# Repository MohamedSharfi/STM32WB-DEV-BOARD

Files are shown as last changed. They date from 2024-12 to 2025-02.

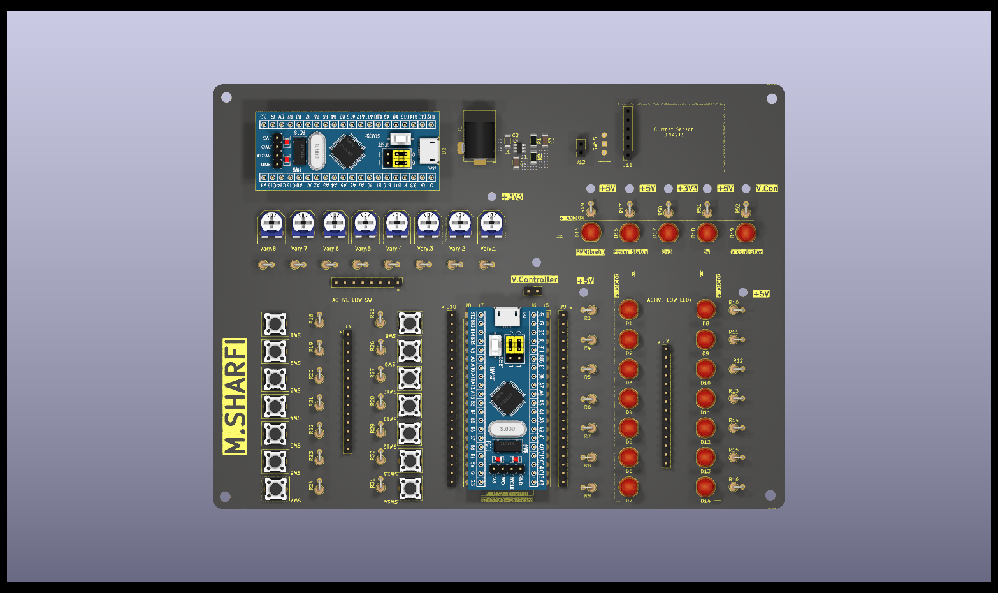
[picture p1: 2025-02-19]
TestBoard/TestBoard.png

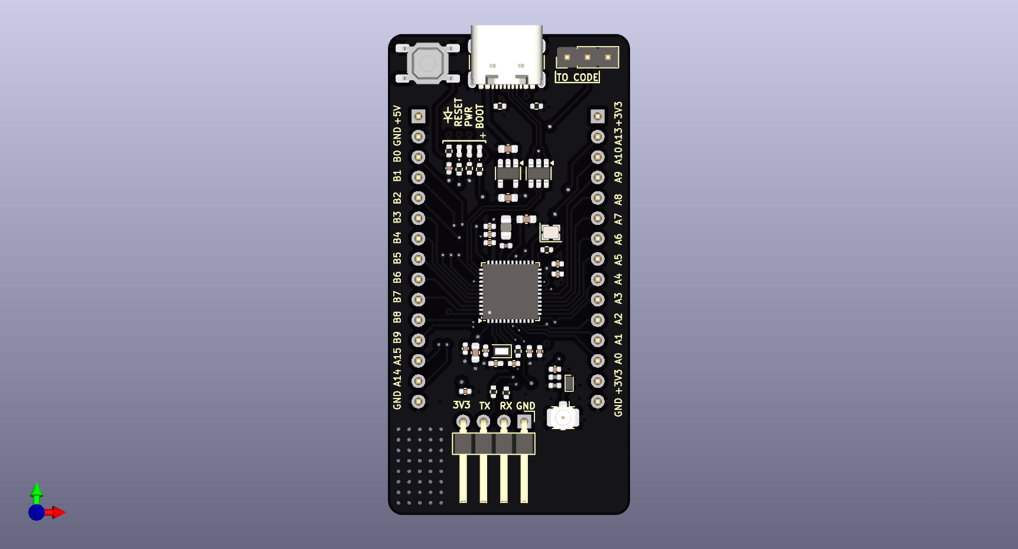
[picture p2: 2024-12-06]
3DPictures/STM32.png

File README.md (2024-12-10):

# STM32 Development Breadboard Prototype 
This repository contains the schematic, PCB design, and documentation for an STM32-based development prototype designed for breadboard testing and prototyping.

## Project Status
     Schematic    :  100% Complete
     PCB Design   :  100% Complete
     Documentation:  100% Complete

## Table of Contents
Overview
Features
Getting Started
Project Files
Documentation
Contributing
License
Overview
This project aims to provide a robust STM32 development environment optimized for breadboard prototyping. It's ideal for my next projects development & testing.

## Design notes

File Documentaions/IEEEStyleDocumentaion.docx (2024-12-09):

STM32 Board Design

Mohamed Sharfi Abdelgadir Omer
Electrical Engineering Student , Universiti Teknologi Malaysia

Abstract—This electronic document is a DETAILED report about the design and development of STM32 PCB board starting from the schematic until the last Gerber files, any more updates of the board and manufacturing process will be added to this report.

Keywords—STM32WB, PCB design, Design Rules, Schematic, layout.

# I. Introduction

STM32, made by STMicroelectronics, is one of the leading products in the industry for microcontroller chip manufacturing. It is crucial for students to learn how to design schematics and layouts for PCBs that meet all the standards set by STMicroelectronics for their microcontrollers. After design process, it is important to test it thoroughly before using it in a project to minimize the time needed for troubleshooting in the future, this paper will focus on the main component design of the schematic of the microcontroller as a development that can be used for future prototypes.

# II. Chip Used

STM32WB55 is an 32-bit Arm®-based Cortex® with Bluetooth 5.4 and IEEE802.15.4 Radio.

It uses 2.4Ghz frequency and can support up to 3.6V.It has a 30 pins GPIO, 12bit ADC with 13 channels (incl. 3 internal) with an internal Vref. It also has a 16-bit timer, one general purpose 32-bit timer, two 16-bit basic timers, two low power timers, two watchdog timers , and a SysTick timer which all of them supports direct memory access (DMA). The Clock sources are 32Mhz crystal oscillator (integrated trimming capacitors) as a radio and CPU clock and 32khz for RTC. The internal Memories, up to 1MB flash memory 256KB sRAM , USART , SPI , I2C and USB interfaces for bootloader.

The Microcontroller is capable of handling the intended projects and its suitable for wireless base friendly projects

# III. Schemtic design

## A. Power sources.

The Main sources for power will be a USB-C which can deliver 5V, but Microcontroller can handle up to 3.6 and it’s recommended to operate at 3.3v so we will regulate that voltage using a linear regulator although the efficiency isn’t the best but its suitable for small low-cost applications.

The chip used is MIC5365-3.3YD5 which has two 4.7uf capacitors and referring to the datasheet both capacitors are used for stability and ripple minimizing purposes.

The regulator can be turned on using the enable pin which is active high that can handle up to Vin, which is 5v,

Lastly an LED has been added to indicate when power is on the next figure shows the circuit of the power regulator.

Then to power the microcontroller we first need to add a couple of decoupling capacitors. The power traces can be affected by EMI and stray inductance which can lead to some fluctuations, Sparkes or noise in the input voltage in the microcontroller

The STM32 datasheet recommended that a bulky capacitor which is 4.7uf need to be placed before the power pins in addition with an 100nf small decoupling capacitor for each pin.

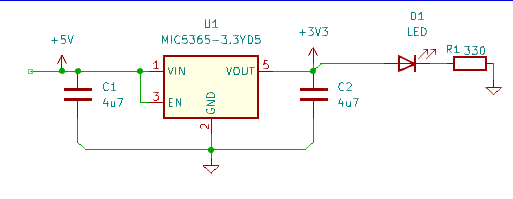
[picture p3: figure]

Figure ‎III-1 Circuit of the power regulator

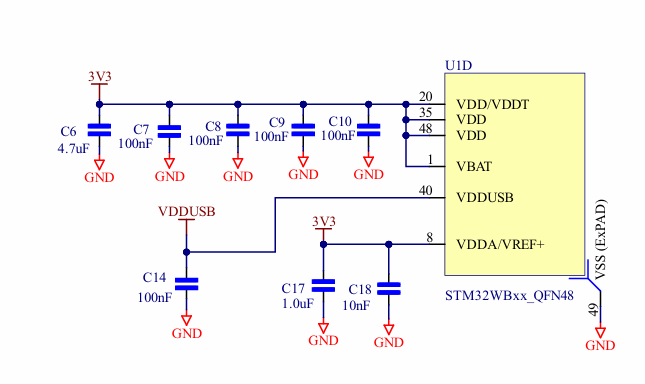
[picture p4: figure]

Figure ‎III-2 Recommended Decoupling capacitor

## B. RF and The antenna.

Referring to the section 3.6.4 from the stm32 datasheet RF pin description the RF pin must be connected to the antenna through a low-pass matching network since the Impedance of the RF chip (Zsource) isn’t 50 ohm but (42-19j Ohm) and referring to the Application note AN5165 figure 8 reference board the matching network used is Low-Pass ∏-Shaped with a Low Pass Filter DLF162500LT-5028A1in series and finally ending with an antenna which is an SMD coaxial connector.

Since the LPF chip isn’t available in KiCad and it’s a critical component a new symbol and footprint needed to be designed and added to the KiCad library.

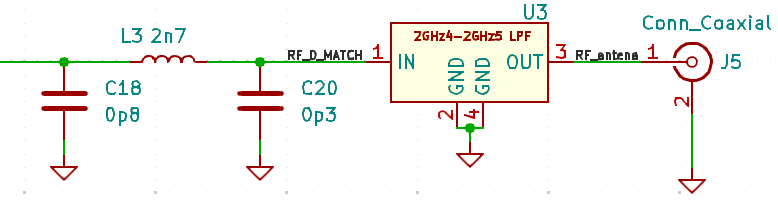
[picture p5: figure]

Figure ‎III-3 Matching Network and LPF circuit

## C. Reset Button

6.3.18 NRST pin characteristics (STM32WB datasheet) clearly shows the circuit for the reset pin NRST which is an Active low pin pulling down will lead to the system to reset.

The recommended circuit is a push button in parrel with a capacitor in order to minimize the debouncing effect, With the recommended circuit an active low LED has been added to indicate the status of the reset pin.

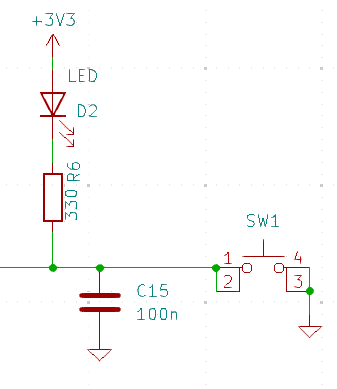
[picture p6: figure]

Figure ‎III-4 Active Low reset button circuit

## D. USB-C connector.

For communication with the Chip, media streaming, Power supply and programming an USB-C connector is needed.CC pins in the type C connector are responsible for determining if your device is receiving power or supplying, and in this case the connector is our main supplier for power, so we need to configure the pins as so. And to do that the pins need to be pulled down. (4.2.5 Configuration Pins). For the ESD we used which is a package containing 5 TVS Diode

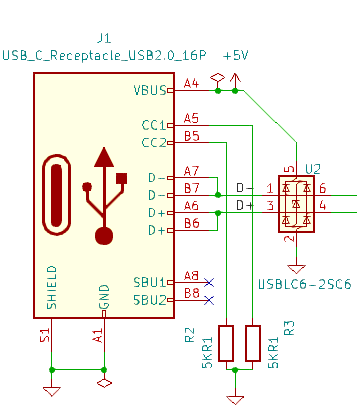
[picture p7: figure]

Figure ‎III-5 USB-C Circuit

## E. Crystal oscillator.

According to the microcontroller datasheet (6.3.10 External clock source characteristics) the high-speed external (HSE) clock should be supplied with a 32 MHz crystal oscillator and the low-speed external (LSE) clock can be supplied with a 32.768 kHz crystal resonator oscillator. Load capacitors affect the resonant frequency and determine the oscillation's stability and phase noise, for the HSE the microcontroller have an integrated tunable load capacitors but for the LSE external load capacitors are needed and referring to AN5165 those value of load capacitors should be 10pF each

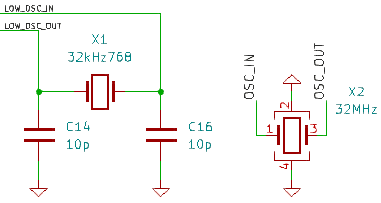
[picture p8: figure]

Figure ‎III-6 crystal oscillator circuits

## F. Switched Mode Power Supply (SMPS).

The device integrates an SMPS step-down converter to improve low power performance

when the VDD voltage is high enough. This converter has an intelligent mode that automatically enters in bypass mode when the VDD voltage falls below a specific BORx (x = 1, 2, 3 or 4) voltage.

By default, at reset, the SMPS is in bypass mode.

The device can be operated without the SMPS by just wiring its output to VDD. This is the case for applications where the voltage is low, or where the power consumption is not critical.

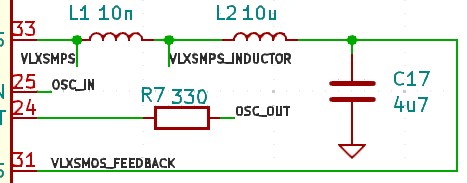
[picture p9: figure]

Figure ‎III-7 SMPS circuit

## G. Boot & program mode

PH3 pin that’s according to the manual is the pin responsible of changing the STM32 statue from normal to bootloader that must be pulled up in order to program the chip using UART. So simply the circuit is an active high 3 pin headers so that when u short the first two STM32 goes to the programming state and if its left floating or grounded it will let the pin operate in normal mode. Additionally, an active high LED is connected to indicate the state of the pin.

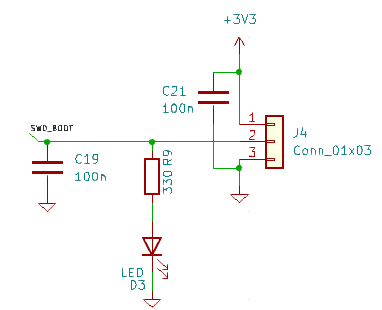
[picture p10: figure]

Figure ‎III-8 PH3 pin

## H. I/O interface

Lastly a 1x15 pin header is added for the GPIO and a 1x4 pin header is added for the UART.

# IV. The Schemtic

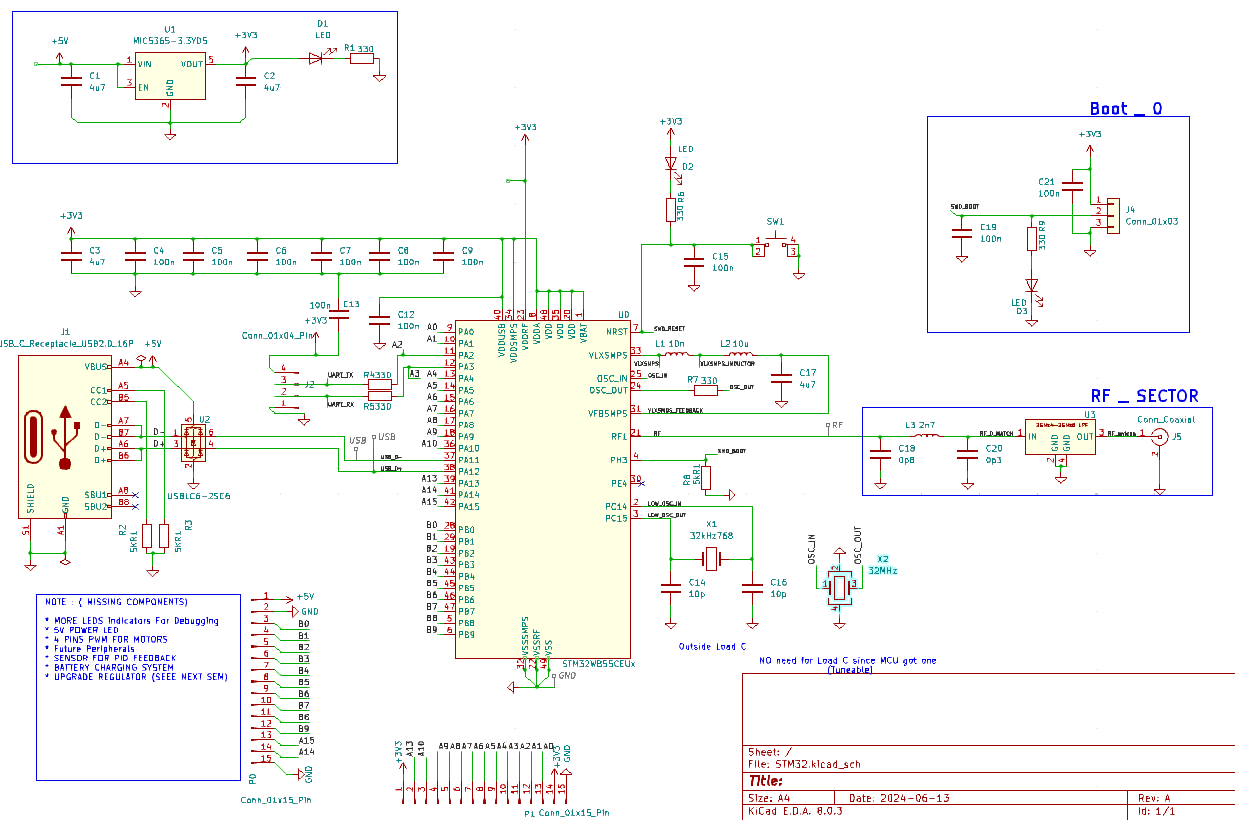
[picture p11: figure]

Figure ‎IV-1 Overall Schematic design

# V. References

[1] Load Capacitance: The Key to Precision in Crystal Units. Avalible : https://www.siward.com/en/about/industry/Load_Capacitance__The_Key_to_Precision_in_Crystal_Units.
[2] AN2606-Application note-STM32 microcontroller system memory boot mode.
[3] STM32WB. Available: https://www.st.com/en/microcontrollers-microprocessors/stm32wb-series/documentation.html.
[4] STMicroelectronics: USBLC6-2.
[5] Universal Serial Bus Type-C Cable and Connector Specification.Avaliable : https://www.usb.org/usbc.
[6] High preformance signle 150mA LDO MIC5365/6. Avalible : https://www.microchip.com/en-us/product/mic5365.
[7] Crystal Unit (32kHz range). Avalible: https://www.ndk.com/en/products/lineup/crystal-unit/NX2012SA-vehicle.html.
[8] Crystial Unit (MHz). avalible : https://www.ndk.com/en/products/lineup/crystal-unit/NX2016SA-standard.html
[9] AN5165 Application note. How to develop RF hardware using STM32WB microcontrollers https://www.st.com/resource/en/application_note/an5165-how-to-develop-rf-hardware-using-stm32wb-microcontrollers-stmicroelectronics.pdf
[10] AN2867 Application note Guidelines for oscillator design on STM8AF/AL/S and STM32 MCUs/MPU avalible : https://www.st.com/resource/en/application_note/an2867-guidelines-for-oscillator-design-on-stm8afals-and-stm32-mcusmpus-stmicroelectronics.pdf

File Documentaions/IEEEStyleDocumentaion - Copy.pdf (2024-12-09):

1

# STM32 Board Design

Mohamed Sharfi Abdelgadir Omer Electrical Engineering Student , Universiti Teknologi Malaysia

Abstract—This electronic document is a DETAILED report about the design and development of STM32 PCB board starting from the schematic until the last Gerber files, any more updates of the board and manufacturing process will be added to this report.
Keywords—STM32WB, PCB design, Design Rules, Schematic, layout.
I. INTRODUCTION
STM32, made by STMicroelectronics, is one of the leading products in the industry for microcontroller chip manufacturing. It is crucial for students to learn how to design schematics and layouts for PCBs that meet all the standards set by STMicroelectronics for their microcontrollers. After design process, it is important to test it thoroughly before using it in a project to minimize the time needed for troubleshooting in the future, this paper will focus on the main component design of the schematic of the microcontroller as a development that can be used for future prototypes.

II. CHIP USED
STM32WB55 is an 32-bit Arm®-based Cortex® with Bluetooth 5.4 and IEEE802.15.4 Radio.
It uses 2.4Ghz frequency and can support up to 3.6V.It has a 30 pins GPIO, 12bit ADC with 13 channels (incl. 3 internal) with an internal Vref. It also has a 16-bit timer, one general purpose 32-bit timer, two 16-bit basic timers, two low power timers, two watchdog timers , and a SysTick timer which all of them supports direct memory access (DMA). The Clock sources are 32Mhz crystal oscillator (integrated trimming capacitors) as a radio and CPU clock and 32khz for RTC. The internal Memories, up to 1MB flash memory 256KB sRAM , USART , SPI , I2C and USB interfaces for bootloader.
The Microcontroller is capable of handling the intended projects and its suitable for wireless base friendly projects

III. SCHEMTIC DESIGN
A. Power sources.
The Main sources for power will be a USB-C which can deliver 5V, but Microcontroller can handle up to 3.6 and it’s recommended to operate at 3.3v so we will regulate that voltage using a linear regulator although the efficiency isn’t the best but its suitable for small low-cost applications.
The chip used is MIC5365-3.3YD5 which has two 4.7uf capacitors and referring to the datasheet both capacitors are used for stability and ripple minimizing purposes.
The regulator can be turned on using the enable pin which is active high that can handle up to Vin, which is 5v,
Lastly an LED has been added to indicate when power is on the next figure shows the circuit of the power regulator. Then to power the microcontroller we first need to add a couple of decoupling capacitors. The power traces can be affected by EMI and stray inductance which can lead to some fluctuations, Sparkes or noise in the input voltage in the microcontroller

The STM32 datasheet recommended that a bulky capacitor which is 4.7uf need to be placed before the power pins in addition with an 100nf small decoupling capacitor for each pin.

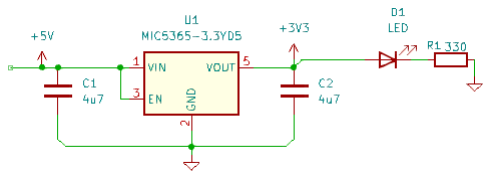
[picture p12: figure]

Figure III-1 Circuit of the power regulator

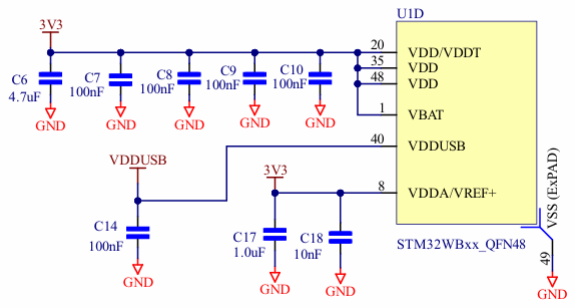
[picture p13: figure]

Figure III-2 Recommended Decoupling capacitor

B. RF and The antenna.
Referring to the section 3.6.4 from the stm32 datasheet RF pin description the RF pin must be connected to the antenna through a low-pass matching network since the Impedance of the RF chip (Zsource) isn’t 50 ohm but (42-19j Ohm) and referring to the Application note AN5165 figure 8 reference board the matching network used is Low-Pass ∏-Shaped with a Low Pass Filter DLF162500LT-5028A1in series and finally ending with an antenna which is an SMD coaxial connector. Since the LPF chip isn’t available in KiCad and it’s a critical component a new symbol and footprint needed to be designed and added to the KiCad library.

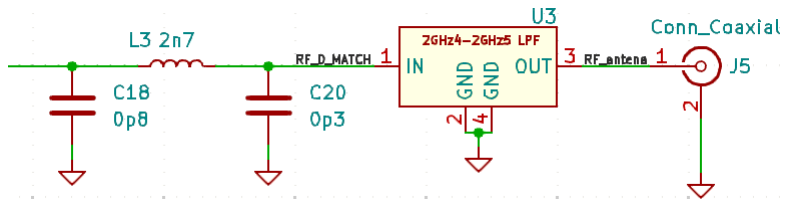
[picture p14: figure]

Figure III-3 Matching Network and LPF circuit
C. Reset Button
6.3.18 NRST pin characteristics (STM32WB datasheet) clearly shows the circuit for the reset pin NRST which is an Active low pin pulling down will lead to the system to reset.

The recommended circuit is a push button in parrel with a capacitor in order to minimize the debouncing effect, With the recommended circuit an active low LED has been added to indicate the status of the reset pin.


Figure III-4 Active Low reset button circuit
D. USB-C connector.
For communication with the Chip, media streaming, Power supply and programming an USB-C connector is needed.CC pins in the type C connector are responsible for determining if your device is receiving power or supplying, and in this case the connector is our main supplier for power, so we need to configure the pins as so. And to do that the pins need to be pulled down. (4.2.5 Configuration Pins). For the ESD we used which is a package containing 5 TVS Diode

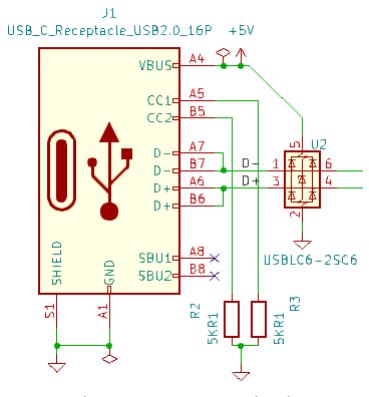
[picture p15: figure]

E. Crystal oscillator.
According to the microcontroller datasheet (6.3.10 External clock source characteristics) the high-speed external (HSE) clock should be supplied with a 32 MHz crystal oscillator and the low-speed external (LSE) clock can be supplied with a 32.768 kHz crystal resonator oscillator. Load capacitors affect the resonant frequency and determine the oscillation's stability and phase noise, for the HSE the microcontroller have an integrated tunable load capacitors but for the LSE external load capacitors are needed and referring to AN5165 those value of load capacitors should be 10pF each

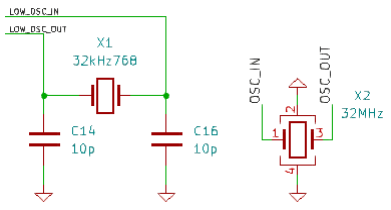
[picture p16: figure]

Figure III-6 crystal oscillator circuits
F. Switched Mode Power Supply (SMPS).
The device integrates an SMPS step-down converter to improve low power performance
when the VDD voltage is high enough. This converter has an intelligent mode that automatically enters in bypass mode when the VDD voltage falls below a specific BORx (x = 1, 2, 3 or 4) voltage.
By default, at reset, the SMPS is in bypass mode.
The device can be operated without the SMPS by just wiring its output to VDD. This is the case for applications where the voltage is low, or where the power consumption is not critical.

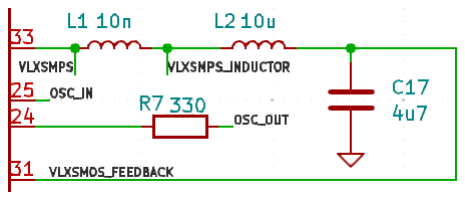
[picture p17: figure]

Figure III-7 SMPS circuit
G. Boot & program mode
PH3 pin that’s according to the manual is the pin responsible of changing the STM32 statue from normal to bootloader that must be pulled up in order to program the chip using UART. So simply the circuit is an active high 3 pin headers so that when u short the first two STM32 goes to the programming state and if its left floating or grounded it will let the pin operate in normal mode. Additionally, an active high LED is connected to indicate the state of the pin.

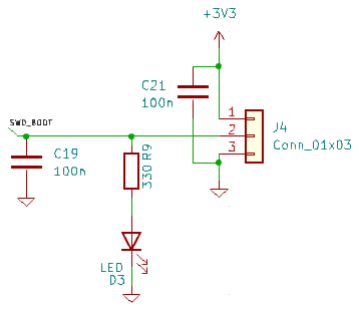
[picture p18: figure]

Figure III-8 PH3 pin

Figure III-5 USB-C Circuit

H. I/O interface
Lastly a 1x15 pin header is added for the GPIO and a 1x4 pin header is added for the UART.

IV. THE SCHEMTIC

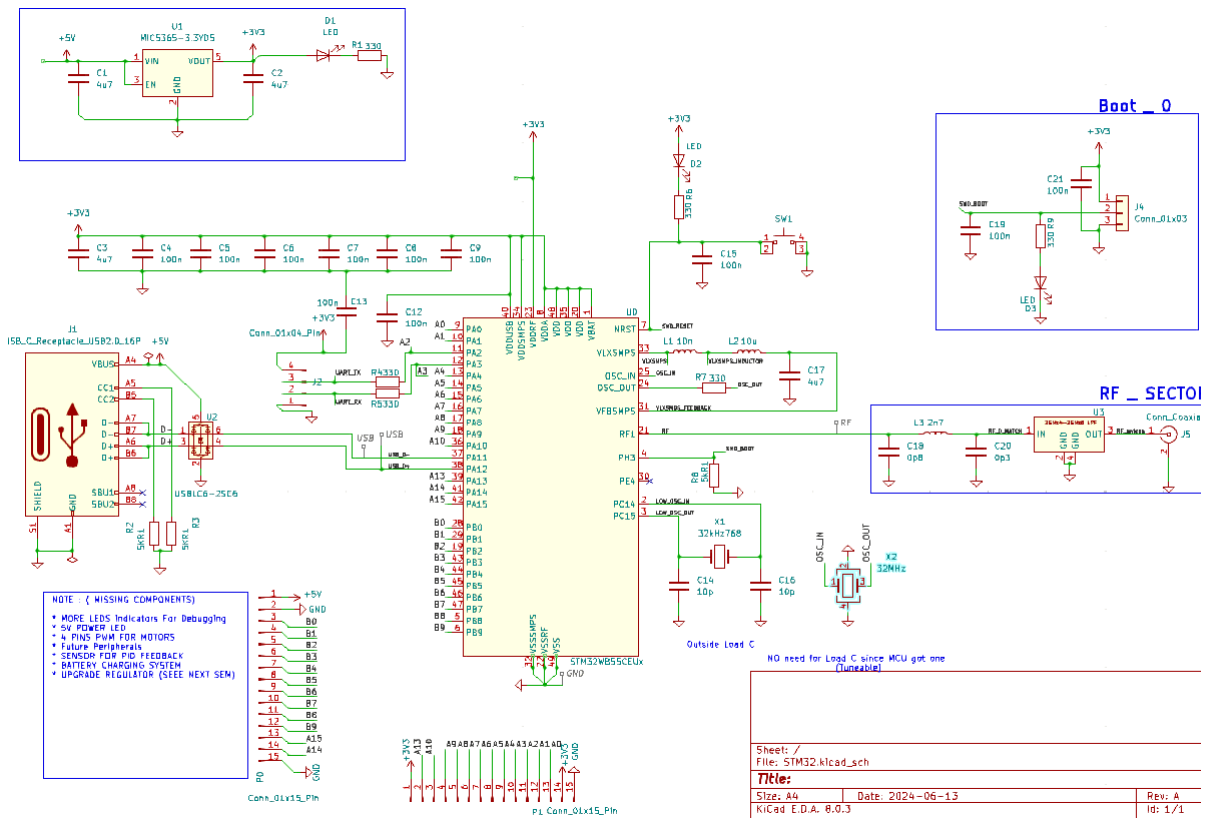
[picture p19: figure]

Figure IV-1 Overall Schematic design

V. REFERENCES
[1] Load Capacitance: The Key to Precision in Crystal Units. Avalible : https://www.siward.com/en/about/industry/Load_Capacitance__The_Key_to_Precision_in_Crystal_Units.
[2] AN2606-Application note-STM32 microcontroller system memory boot mode.
[3] STM32WB. Available: https://www.st.com/en/microcontrollersmicroprocessors/stm32wb-series/documentation.html.
[4] STMicroelectronics: USBLC6-2.
[5] Universal Serial Bus Type-C Cable and Connector Specification.Avaliable : https://www.usb.org/usbc.
[6] High preformance signle 150mA LDO MIC5365/6. Avalible : https://www.microchip.com/en-us/product/mic5365.
[7] Crystal Unit (32kHz range). Avalible: https://www.ndk.com/en/products/lineup/crystal-unit/NX2012SAvehicle.html. (https://www.ndk.com/en/products/lineup/crystal-unit/NX2012SA-vehicle.html)
[8] Crystial Unit (MHz). avalible : https://www.ndk.com/en/products/lineup/crystal-unit/NX2016SAstandard.html (https://www.ndk.com/en/products/lineup/crystal-unit/NX2016SA-standard.html)
[9] AN5165 Application note. How to develop RF hardware using STM32WB microcontrollers
https://www.st.com/resource/en/application_note/an5165-how-todevelop-rf-hardware-using-stm32wb-microcontrollersstmicroelectronics.pdf (https://www.st.com/resource/en/application_note/an5165-how-to-develop-rf-hardware-using-stm32wb-microcontrollers-stmicroelectronics.pdf)
[10] AN2867 Application note Guidelines for oscillator design on STM8AF/AL/S and STM32 MCUs/MPU avalible : https://www.st.com/resource/en/application_note/an2867-guidelinesfor-oscillator-design-on-stm8afals-and-stm32-mcusmpusstmicroelectronics.pdf

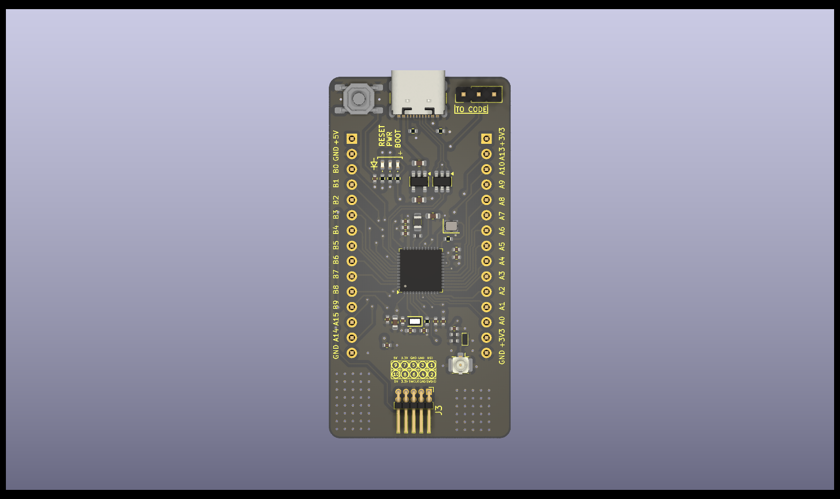
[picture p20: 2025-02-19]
3DPictures/latest version.png

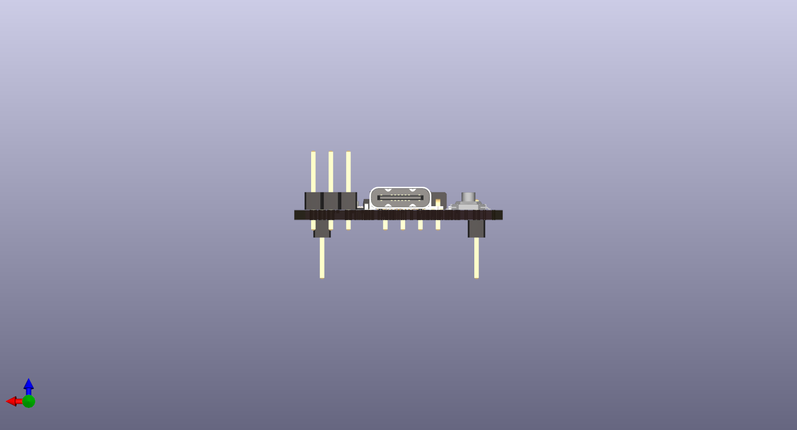
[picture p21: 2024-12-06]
3DPictures/STM32front2.png

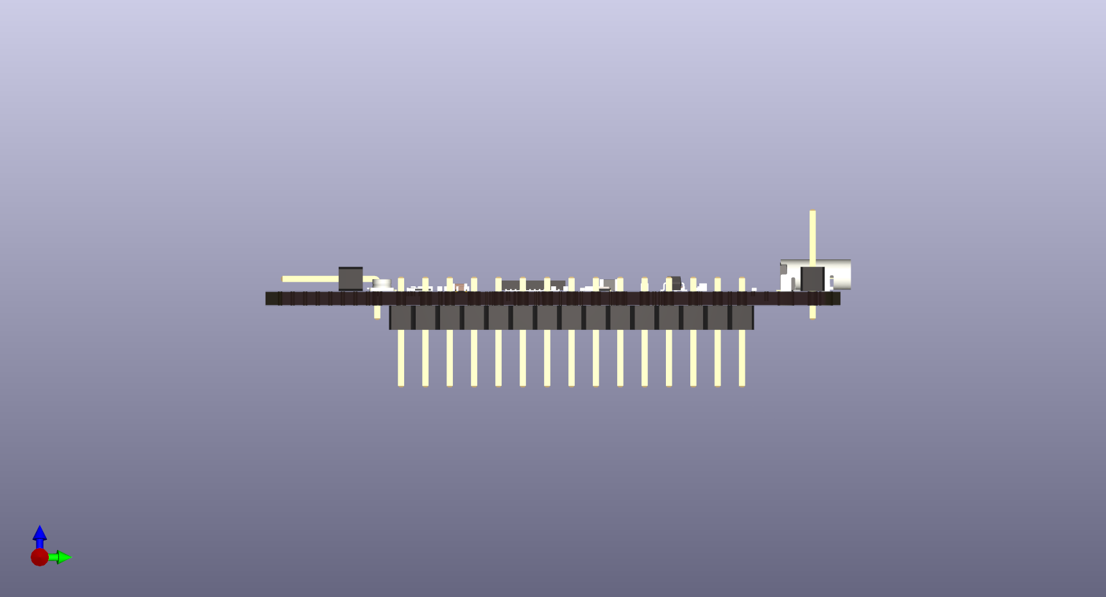
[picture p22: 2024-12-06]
3DPictures/STM32sidet1.png

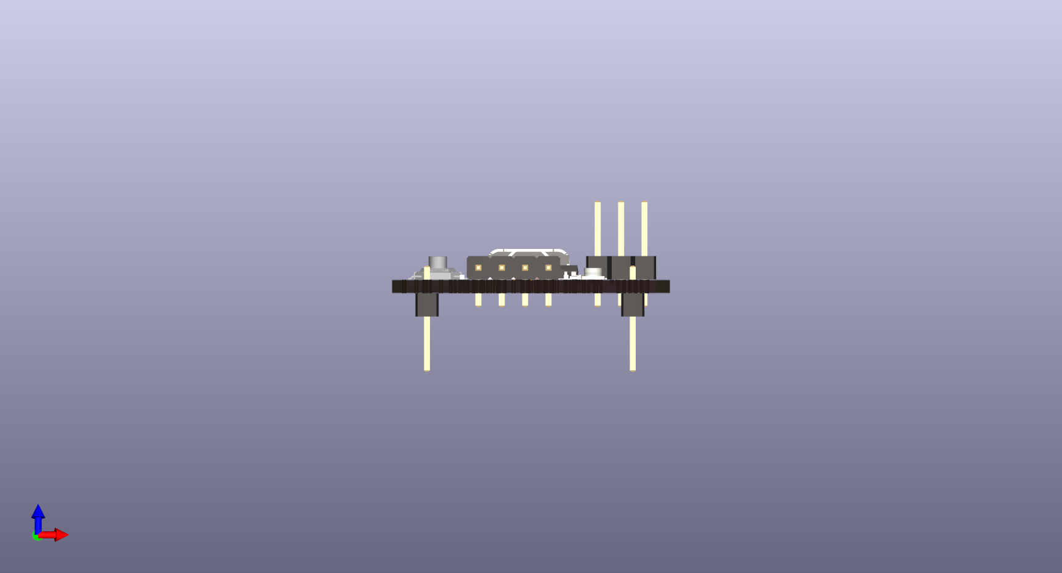
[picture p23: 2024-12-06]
3DPictures/STM32front1.png

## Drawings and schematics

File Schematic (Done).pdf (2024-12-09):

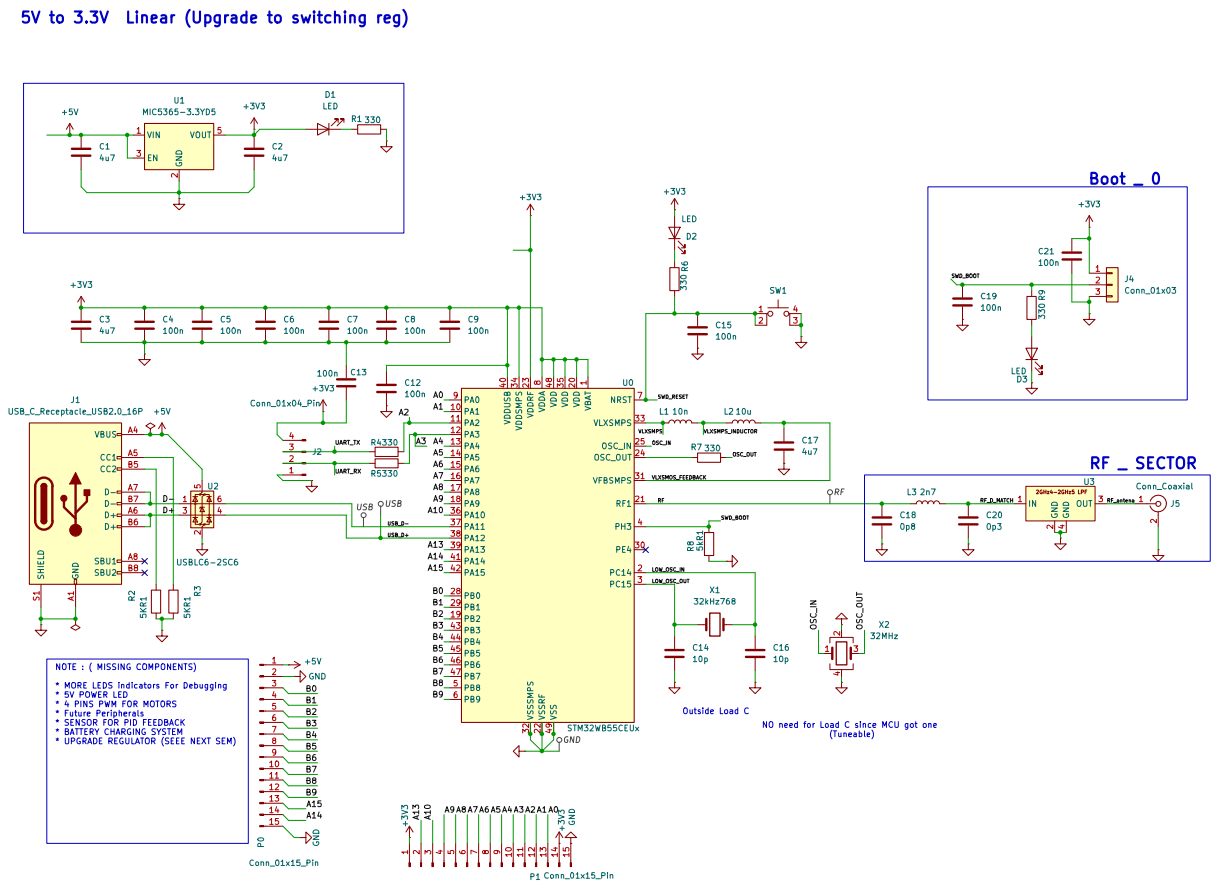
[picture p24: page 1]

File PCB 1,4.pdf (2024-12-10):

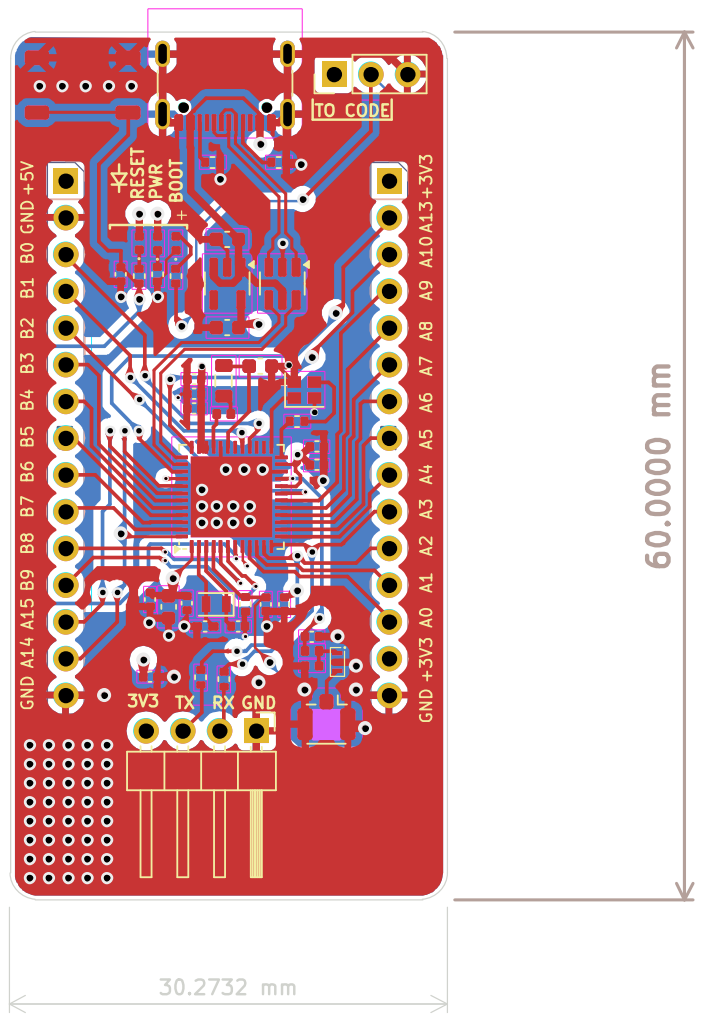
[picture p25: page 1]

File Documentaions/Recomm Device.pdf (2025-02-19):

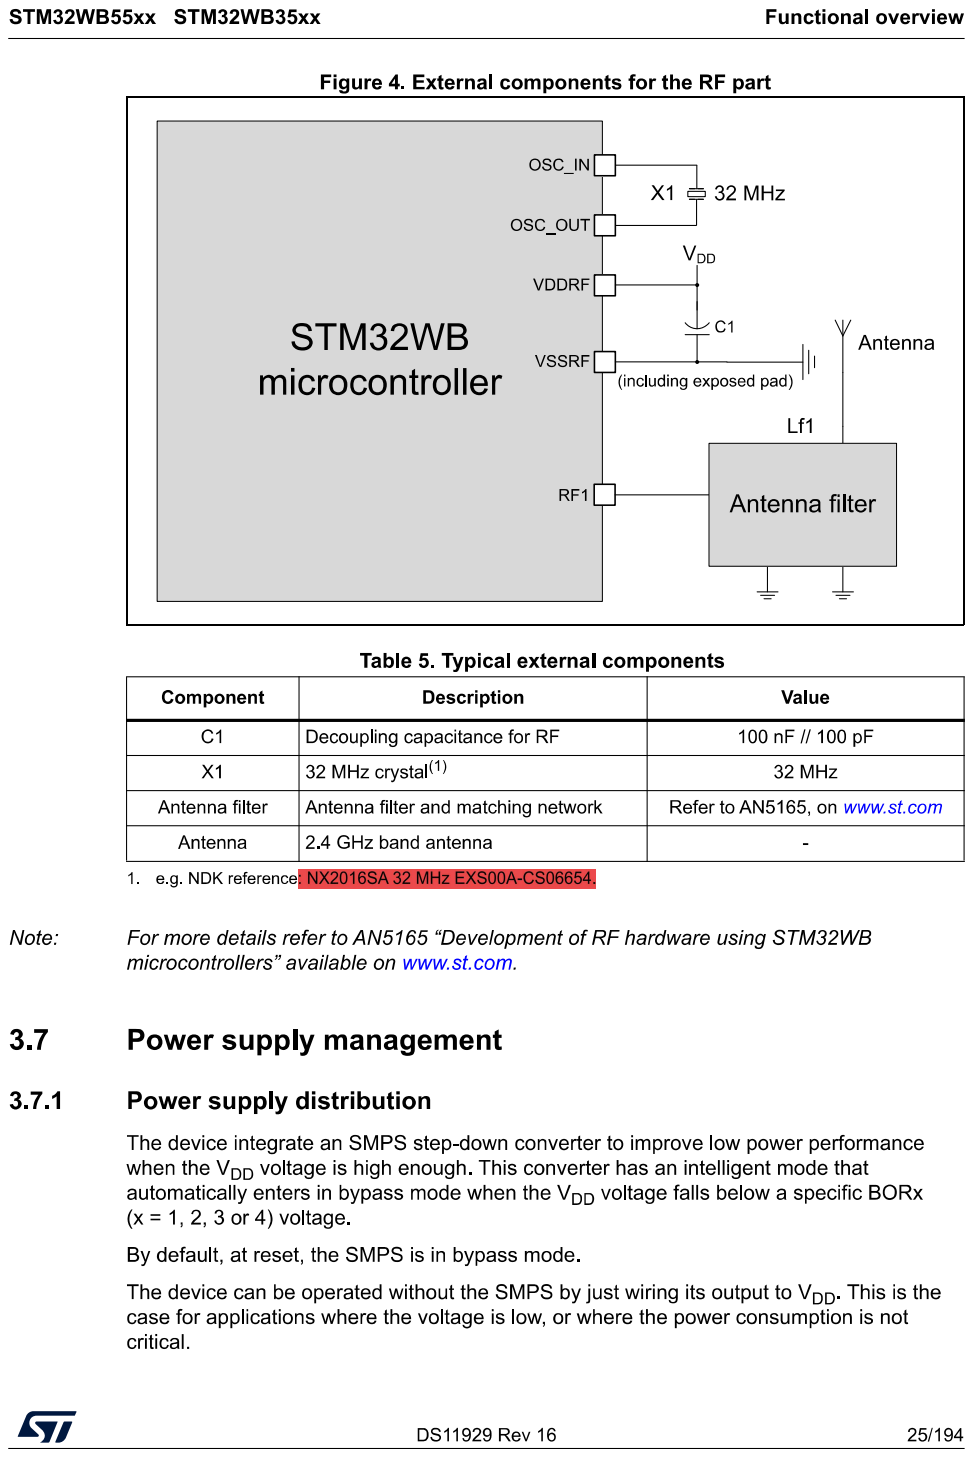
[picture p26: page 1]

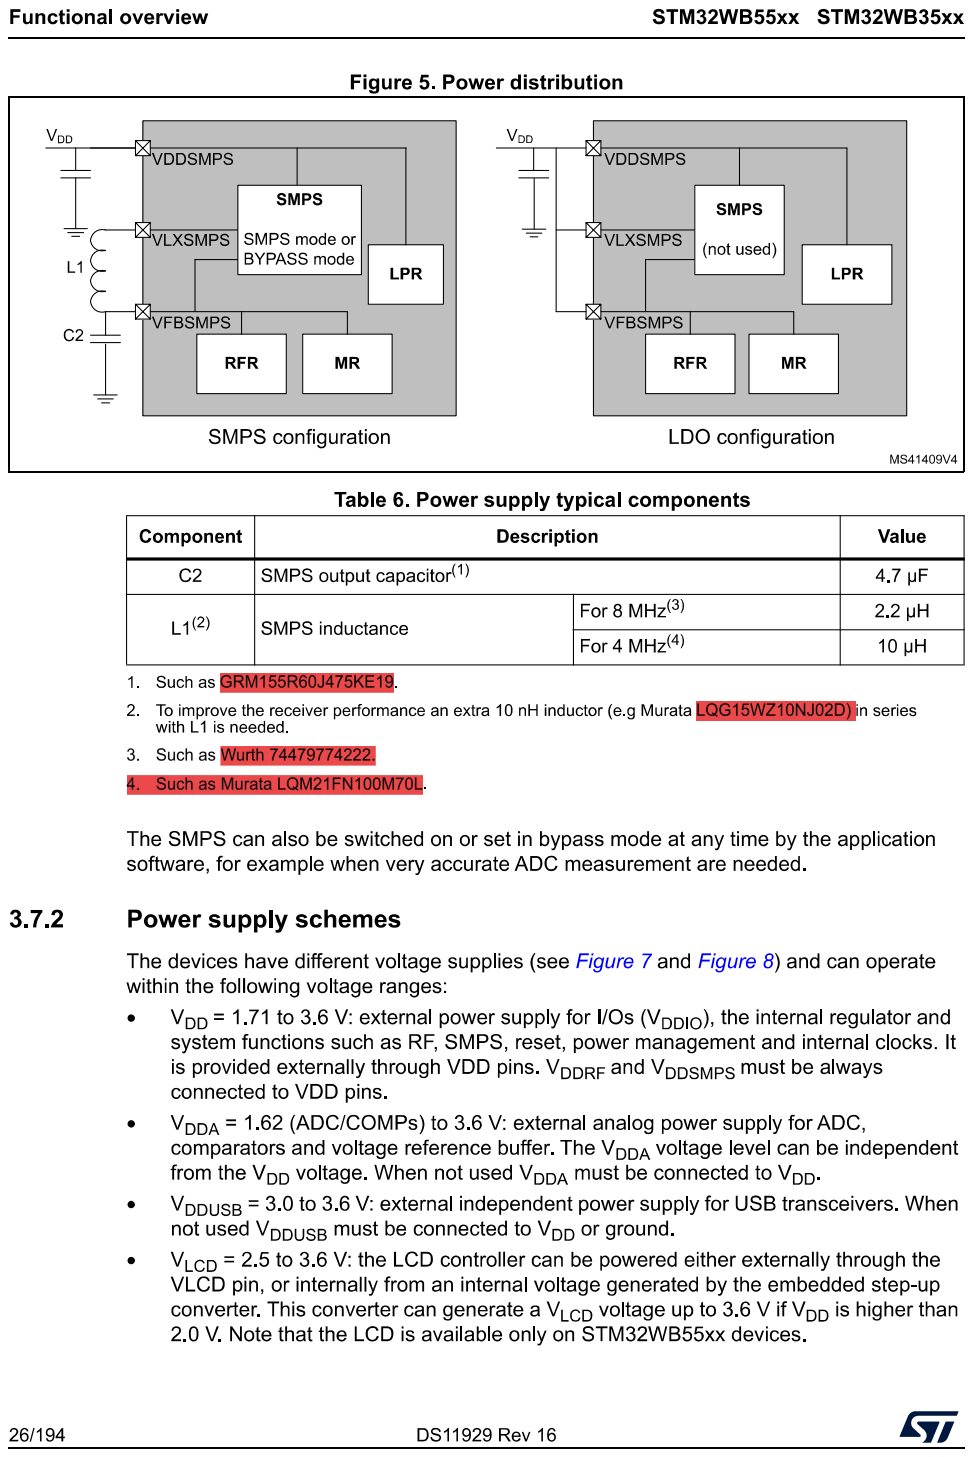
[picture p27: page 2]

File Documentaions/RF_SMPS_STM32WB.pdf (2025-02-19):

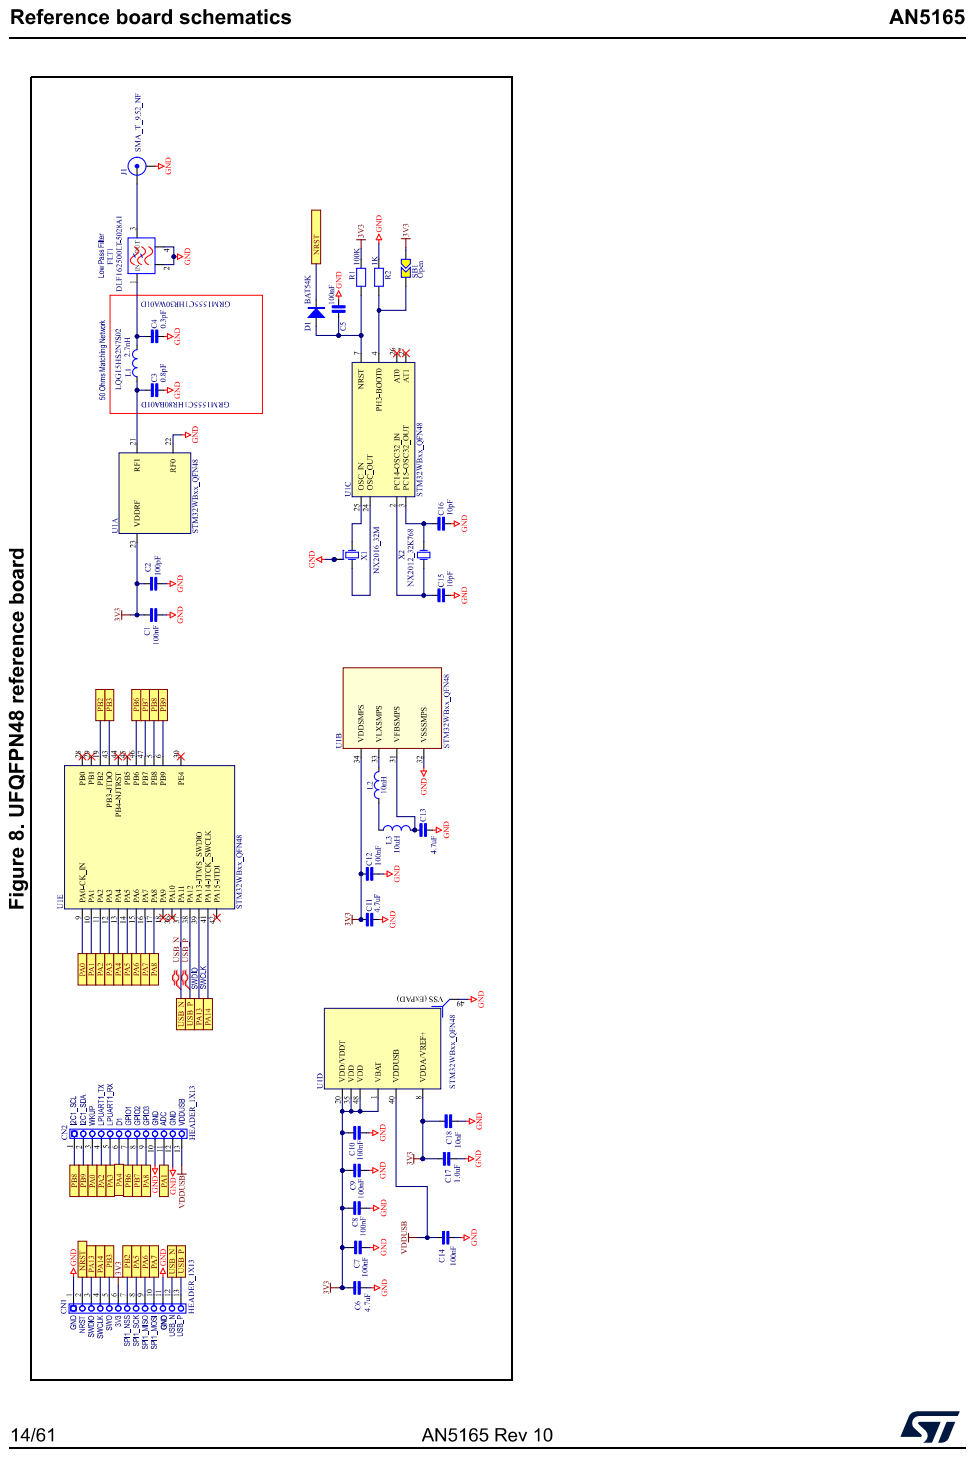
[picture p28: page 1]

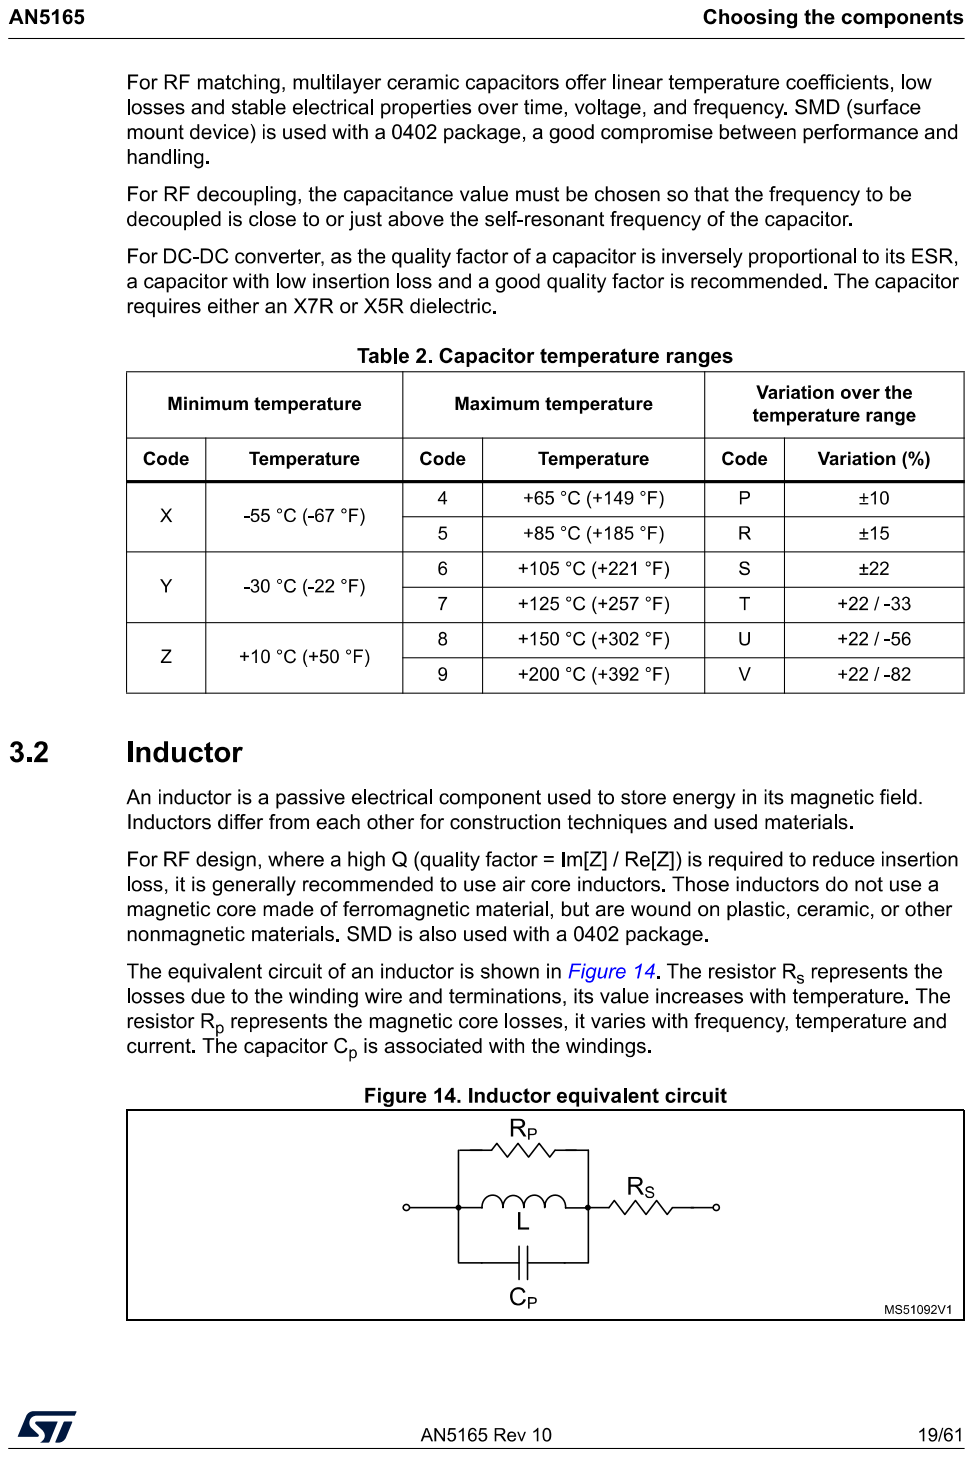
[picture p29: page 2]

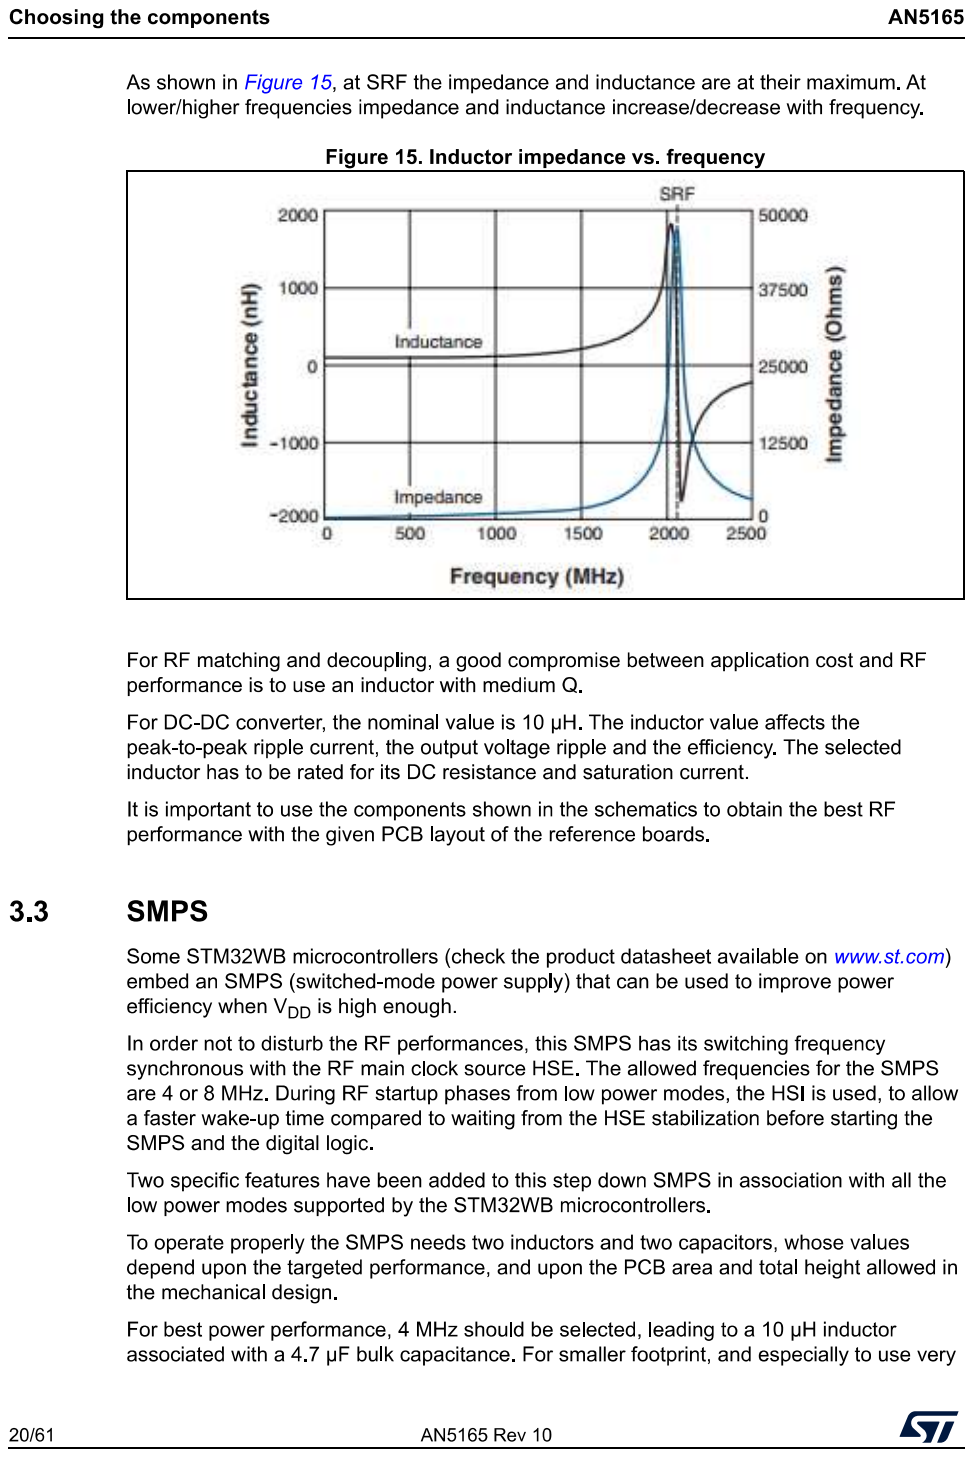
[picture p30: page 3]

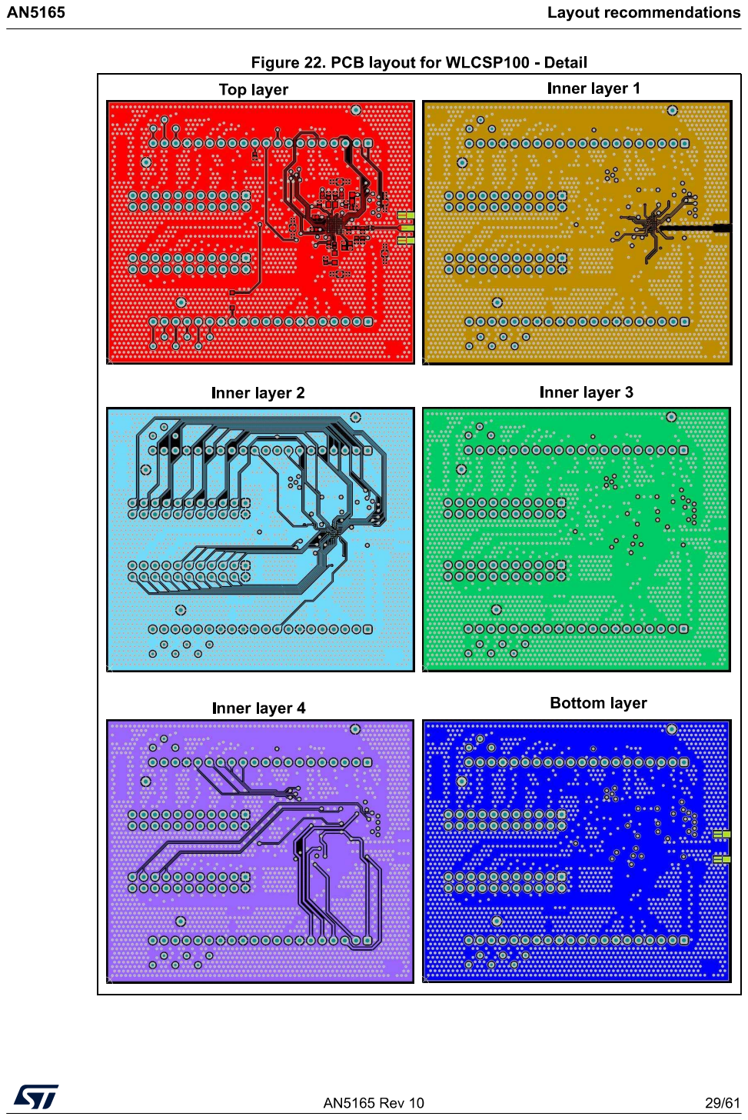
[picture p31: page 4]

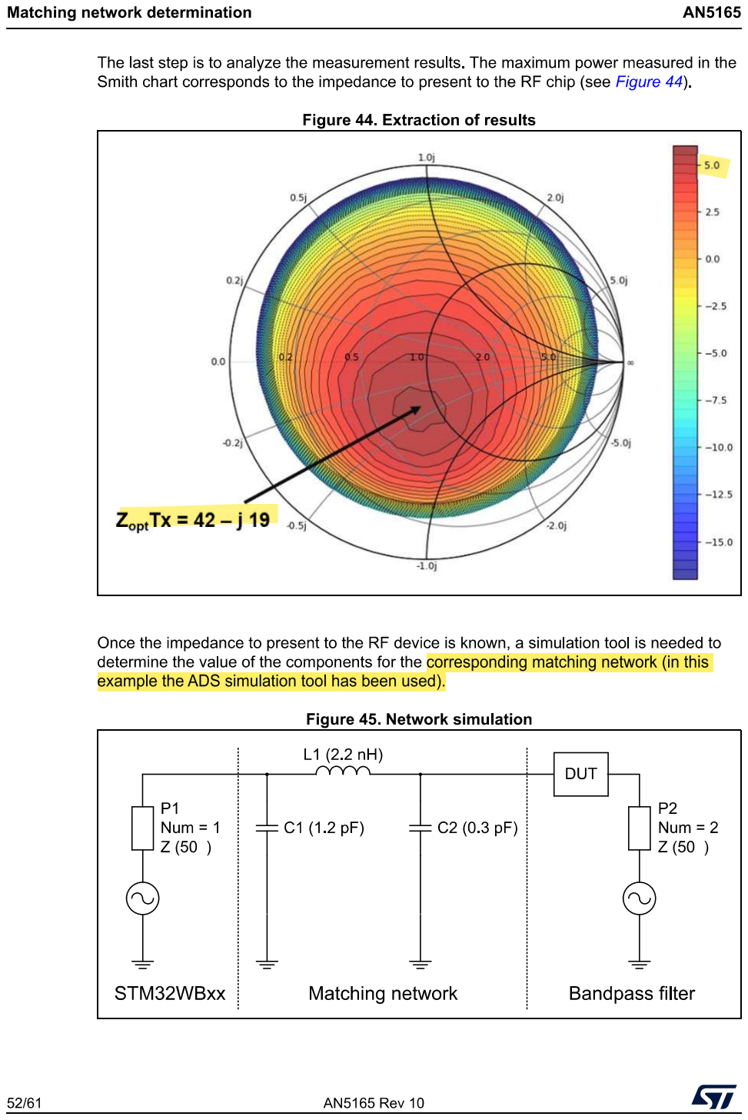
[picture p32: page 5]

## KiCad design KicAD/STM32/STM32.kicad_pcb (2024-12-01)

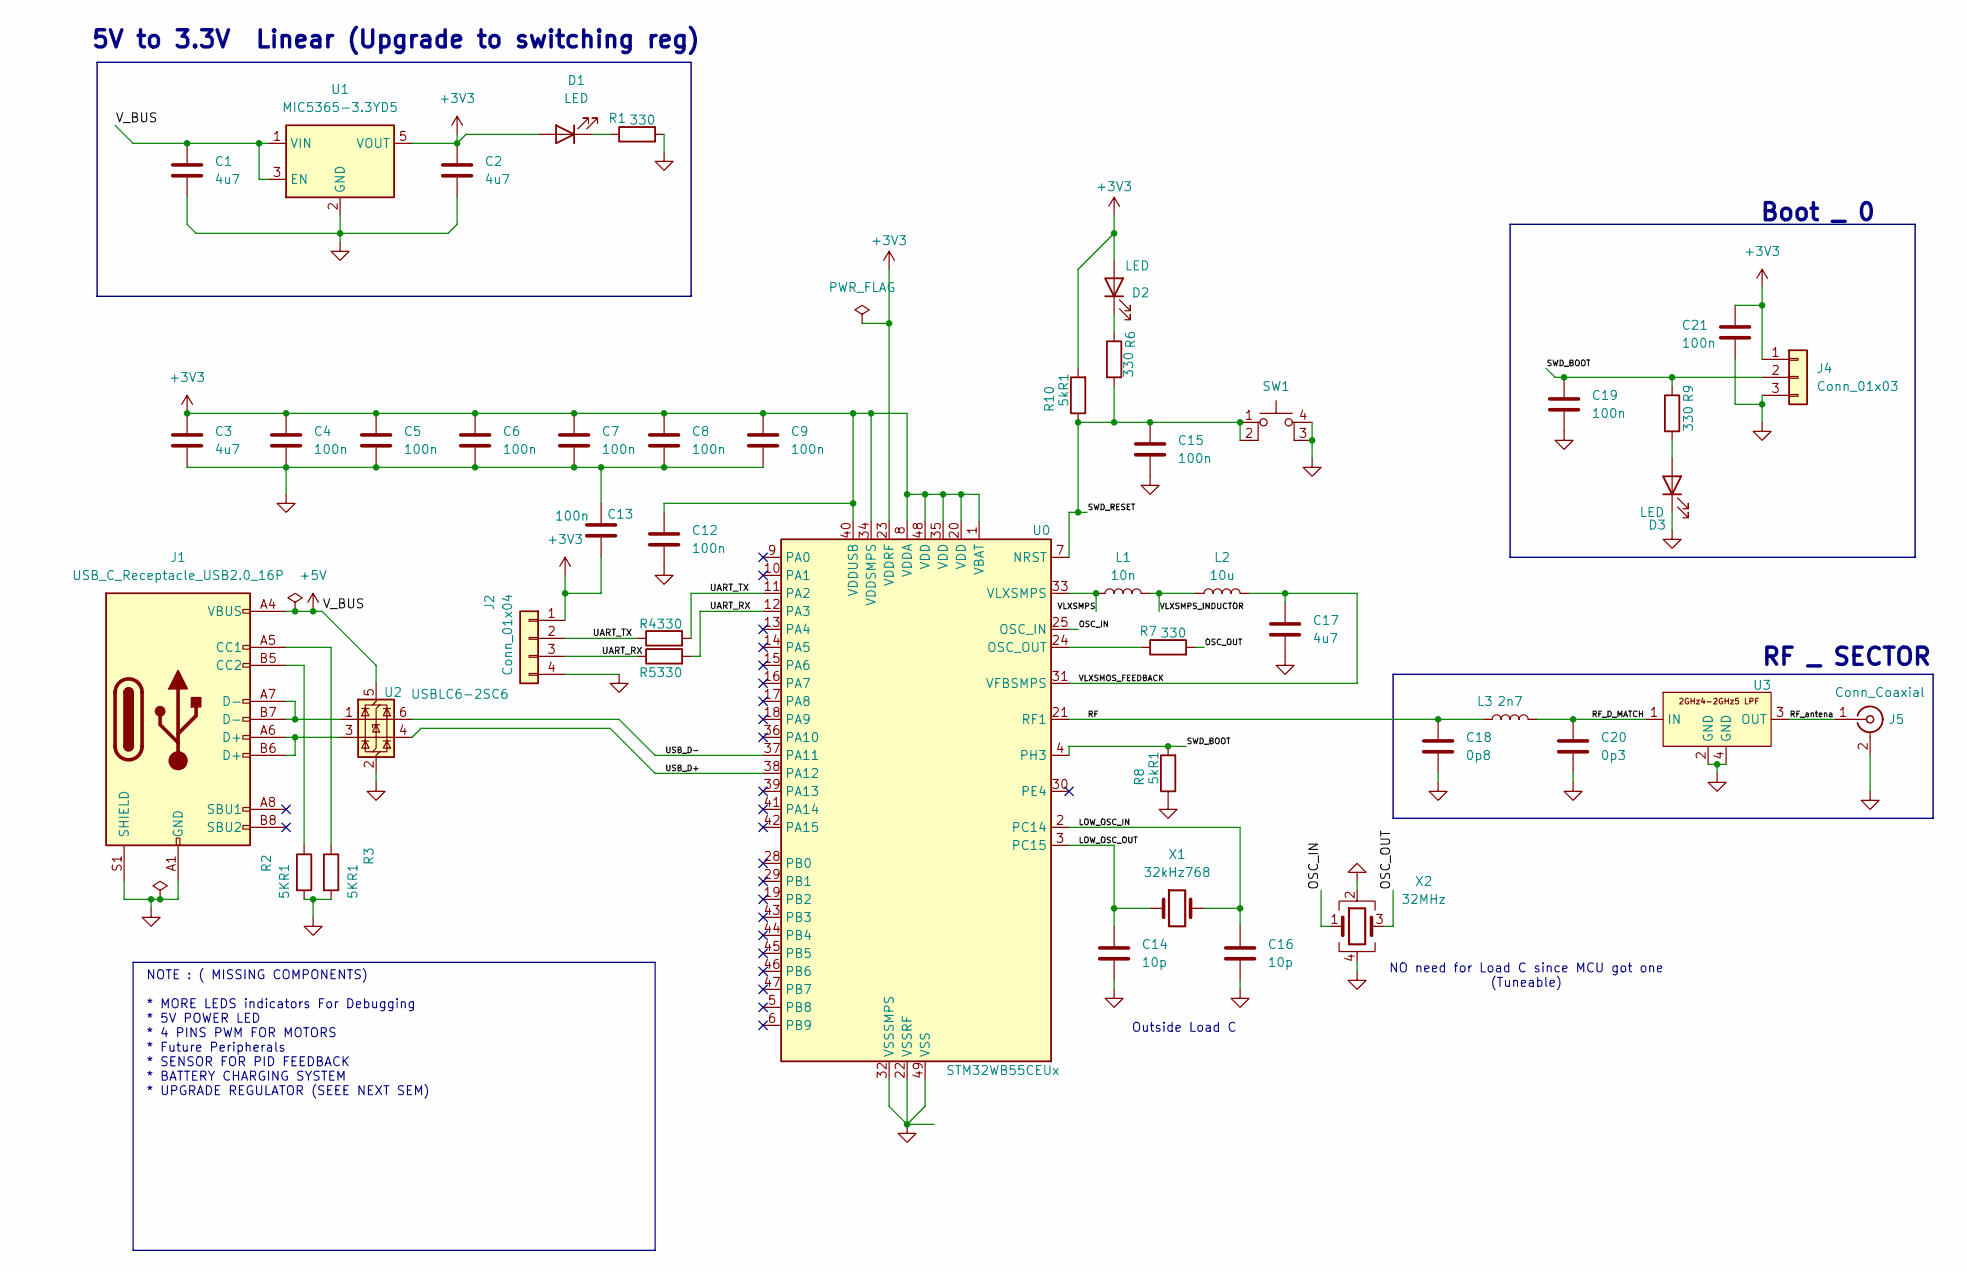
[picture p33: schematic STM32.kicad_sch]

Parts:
C1, C2, C3, C17: 4u7; C_0603_1608Metric
C4, C5, C6, C7, C8, C9, C12, C13, C15, C19, C21: 100n; C_0402_1005Metric
C14: 10p; C_0402_1005Metric
C16: 10p; C_0402_1005Metric_Pad0.74x0.62mm_HandSolder
C18: 0p8; C_0402_1005Metric
C20: 0p3; L_0402_1005Metric
D1, D2, D3: LED; LED_0402_1005Metric
J1: USB_C_Receptacle_USB2.0_16P; USB_C_Receptacle_GCT_USB4105-xx-A_16P_TopMnt_Horizontal
J2: Conn_01x04; Molex_PicoBlade_53048-0410_1x04_P1.25mm_Horizontal
J4: Conn_01x03; PinHeader_1x03_P2.54mm_Vertical
J5: Conn_Coaxial; U.FL_Hirose_U.FL-R-SMT-1_Vertical
L1: 10n; L_0402_1005Metric
L2: 10u; L_0805_2012Metric
L3: 2n7; L_0402_1005Metric
R1, R4, R5, R6, R7, R9: 330; R_0402_1005Metric
R2, R3: 5KR1; R_0402_1005Metric
R8, R10: 5kR1; R_0402_1005Metric
SW1: SW_MEC_5E; TS18-5-25-SL-260-SMT-TR
U0: STM32WB55CEUx; QFN-48-1EP_7x7mm_P0.5mm_EP5.6x5.6mm; Part Number STM32WB55CEU6
U1: MIC5365-3.3YD5; SOT-23-5; Part Number MIC5365-3.3YD5-TR
U2: USBLC6-2SC6; SOT-23-6; Part Number USBLC6-2SC6
U3: DLF162500LT-5028A1; Part Number DLF162500LT-5028A1
X1: 32kHz768; Crystal_SMD_2012-2Pin_2.0x1.2mm; Part Number NX2012SA-32.768K-STD-MUB-1
X2: 32MHz; Crystal_SMD_2016-4Pin_2.0x1.6mm; Part Number NX2016SA-32M-EXS00A-CS06465

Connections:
+3V3: C2.1, C3.1, C4.1, C5.1, C6.1, C7.1, C8.1, C9.1, C12.1, C13.2, C21.1, D1.2 (A), D2.2 (A), J2.1, J4.1, R10.2, U0.1 (VBAT), U0.8 (VDDA), U0.20 (VDD), U0.23 (VDDRF), U0.34 (VDDSMPS), U0.35 (VDD), U0.40 (VDDUSB), U0.48 (VDD), U1.5 (VOUT)
+5V: C1.1, J1.A4 (VBUS), J1.A9 (VBUS), J1.B4 (VBUS), J1.B9 (VBUS), U1.1 (VIN), U1.3 (EN), U2.5 (VBUS)
/LOW_OSC_IN: C16.1, U0.2 (PC14), X1.2
/LOW_OSC_OUT: C14.1, U0.3 (PC15), X1.1
/OSC_IN: U0.25 (OSC_IN), X2.1
/OSC_OUT: R7.2, X2.3
/RF: C18.1, L3.1, U0.21 (RF1)
/RF_D_MATCH: C20.1, L3.2, U3.1 (IN)
/RF_antena: J5.1 (In), U3.3 (OUT)
/SWD_BOOT: C19.1, J4.2, R8.2, R9.1, U0.4 (PH3)
/SWD_RESET: C15.1, R6.2, R10.1, SW1.1, SW1.2, U0.7 (NRST)
/UART_RX: J2.3, R5.1, R5.2, U0.12 (PA3)
/UART_TX: J2.2, R4.1, R4.2, U0.11 (PA2)
/USB_D+: U0.38 (PA12), U2.4 (I/O2)
/USB_D-: U0.37 (PA11), U2.6 (I/O1)
/VLXSMOS_FEEDBACK: C17.1, L2.2, U0.31 (VFBSMPS)
/VLXSMPS: L1.1, U0.33 (VLXSMPS)
/VLXSMPS_INDUCTOR: L1.2, L2.1
GND: C1.2, C2.2, C3.2, C4.2, C5.2, C6.2, C7.2, C8.2, C9.2, C12.2, C13.1, C14.2, C15.2, C16.2, C17.2, C18.2, C19.2, C20.2, C21.2, D3.1 (K), J1.A1 (GND), J1.A12 (GND), J1.B1 (GND), J1.B12 (GND), J1.S1 (SHIELD), J2.4, J4.3, J5.2 (Ext), R1.2, R2.2, R3.2, R8.1, SW1.3 (K), SW1.4 (A), U0.22 (VSSRF), U0.32 (VSSSMPS), U0.49 (VSS), U1.2 (GND), U2.2 (GND), U3.2 (GND), U3.4 (GND), X2.2, X2.4
unnamed: D1.1 (K), R1.1
unnamed: D2.1 (K), R6.1
unnamed: D3.2 (A), R9.2
unnamed: J1.A5 (CC1), R3.1
unnamed: J1.B5 (CC2), R2.1
unnamed: J1.A6 (D+), J1.B6 (D+), U2.3 (I/O2)
unnamed: J1.A7 (D-), J1.B7 (D-), U2.1 (I/O1)
unnamed: R7.1, U0.24 (OSC_OUT)

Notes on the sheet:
5V to 3.3V Linear (Upgrade to switching reg)
RF _ SECTOR
NOTE : ( MISSING COMPONENTS) * MORE LEDS indicators For Debugging * 5V POWER LED * 4 PINS PWM FOR MOTORS * Future Peripherals * SENSOR FOR PID FEEDBACK * BATTERY CHARGING SYSTEM * UPGRADE REGULATOR (SEEE NEXT SEM)
NO need for Load C since MCU got one (Tuneable)
Boot _ 0
Outside Load C

Board: 2 copper layers, 46 parts (0 on the bottom side), 27 nets, no tracks yet.
